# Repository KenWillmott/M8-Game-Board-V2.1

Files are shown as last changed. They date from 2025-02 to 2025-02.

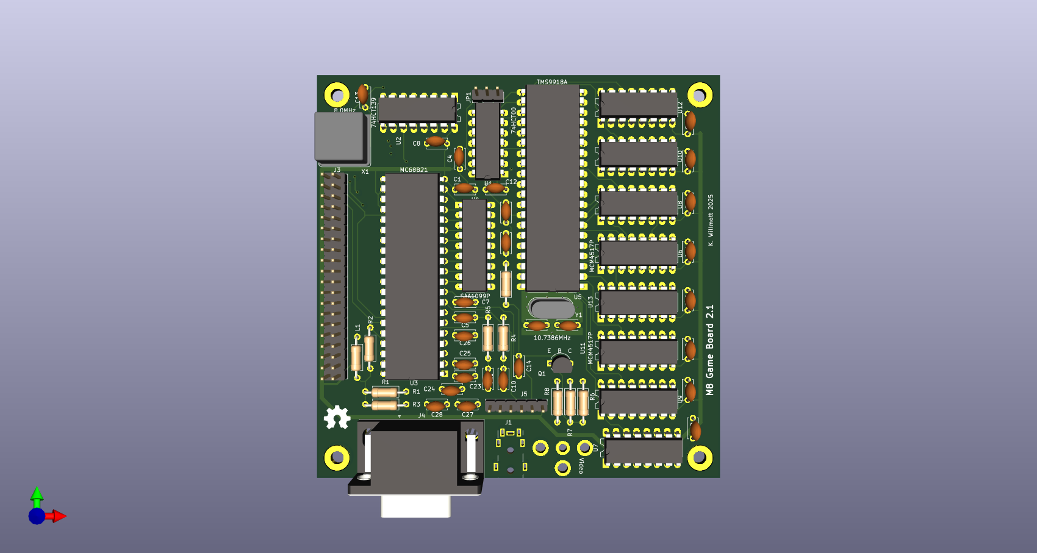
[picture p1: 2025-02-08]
motorino-game-3d.png

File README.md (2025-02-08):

# M8-Game-Board-V2.1
Audio Video Joystick card for M8 bus


This board replaces the first game board, which was not fully working or fully M8 compatible.

It has a TMS9918A video processor with composite video output, stereo sound output from a Philips SAA1099 IC, and one Atari style joystick port. The sound IC and joystick are interfaced via an MC6821 PIA.

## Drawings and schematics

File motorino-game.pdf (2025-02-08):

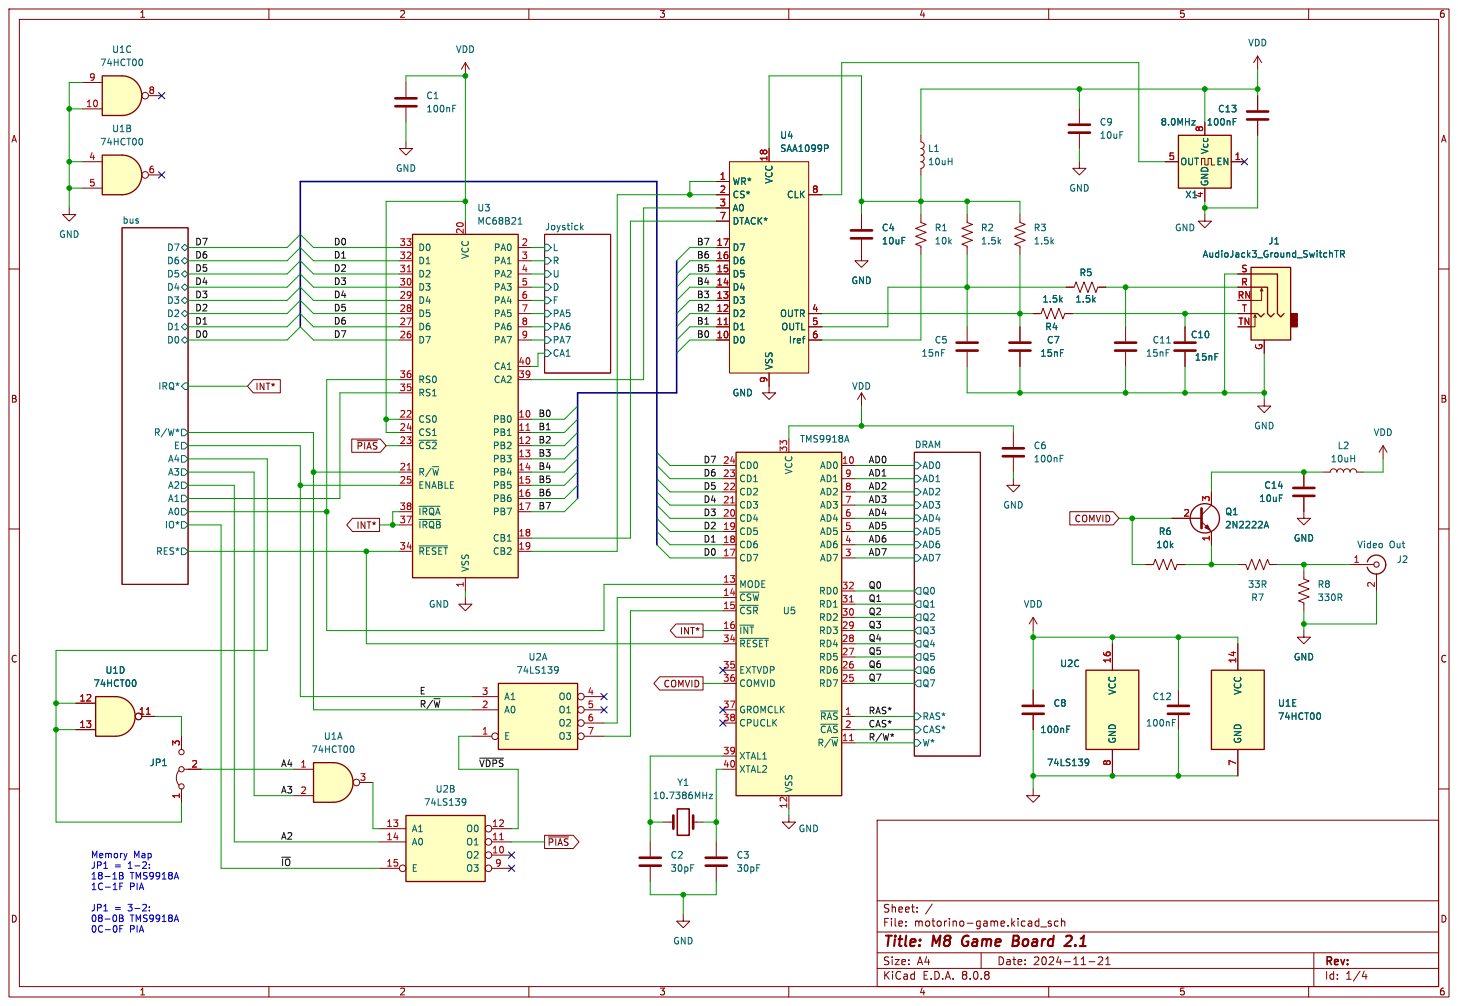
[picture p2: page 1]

File: motorino-game.kicad_sch Sheet: /AD7 AD1 AD2 AD3 AD4 AD5 AD6 AD0 W* RAS* CAS* Q0 Q3 Q1 Q2 Q6 Q7 Q4 Q5 DRAM

Id: 1/4 Title: M8 Game Board 2.1

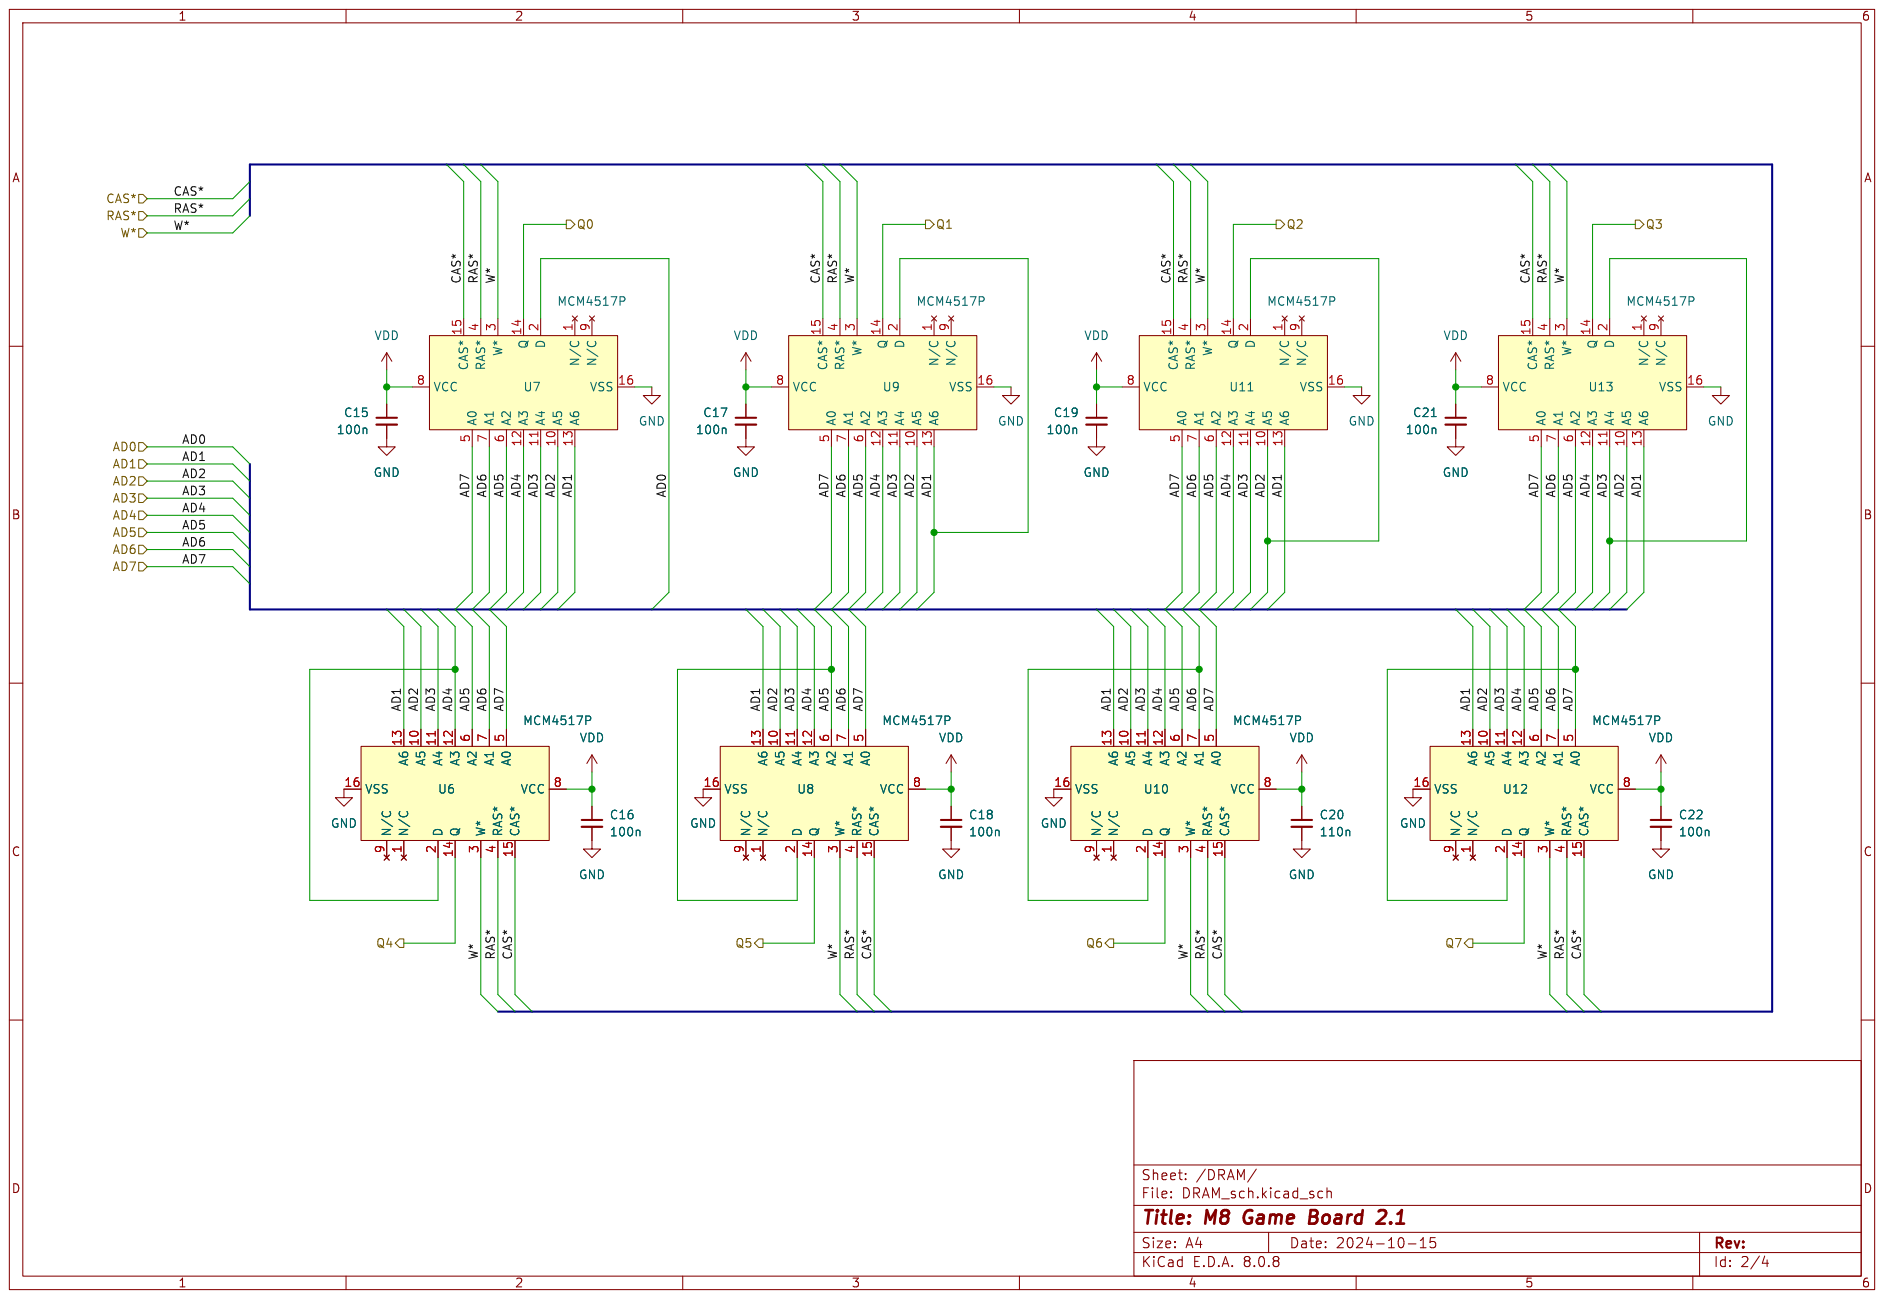
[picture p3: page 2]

Id: 2/4 Title: M8 Game Board 2.1

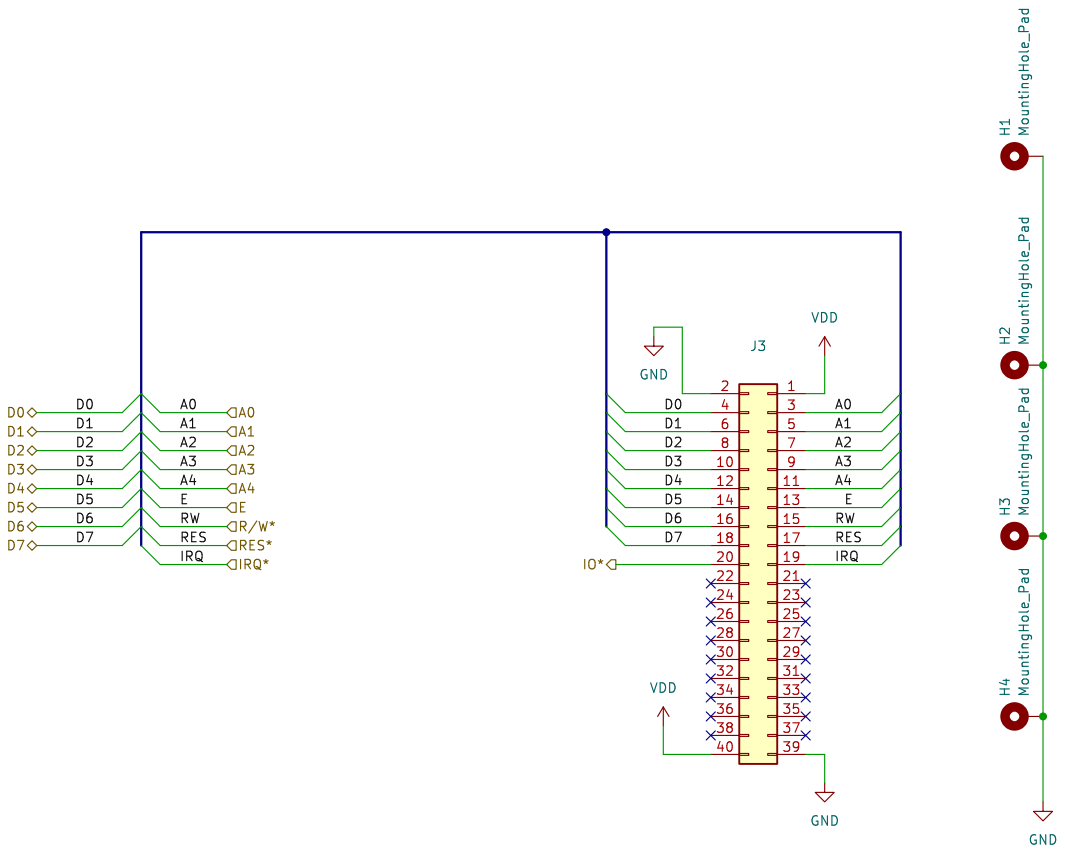
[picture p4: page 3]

Id: 3/4 Title: M8 Game Board 2.1

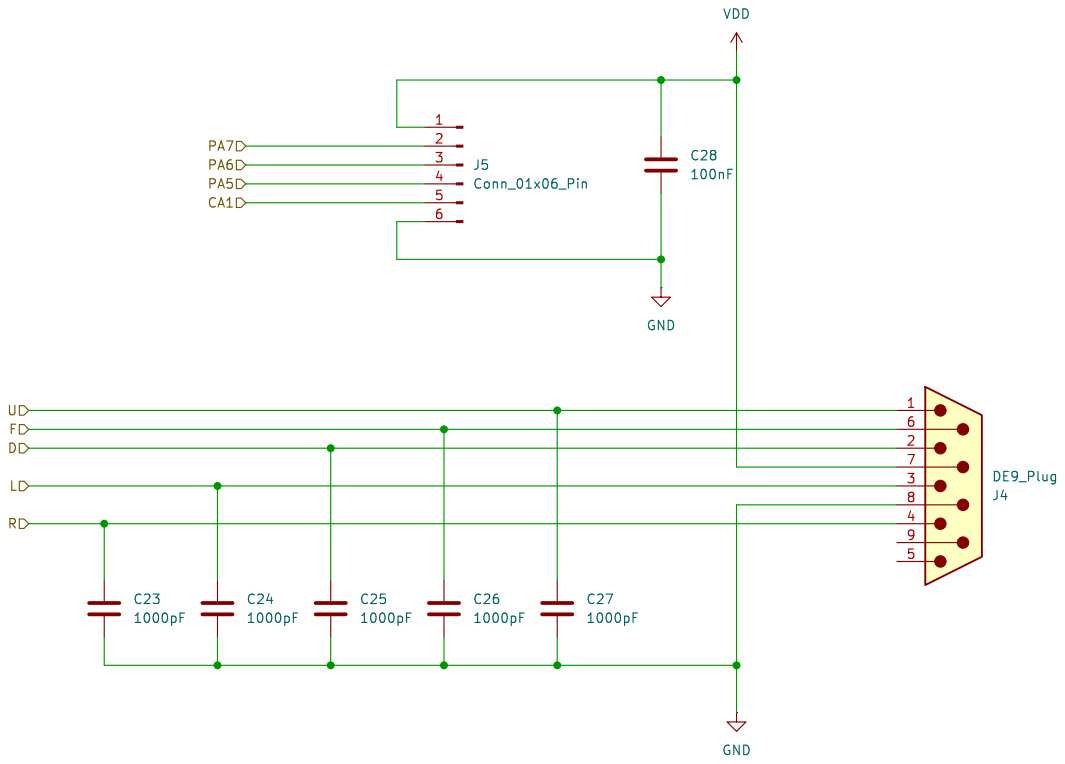
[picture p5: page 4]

Id: 4/4 Title: File: Joystick_sch.kicad_sch Sheet: /Joystick/ C25

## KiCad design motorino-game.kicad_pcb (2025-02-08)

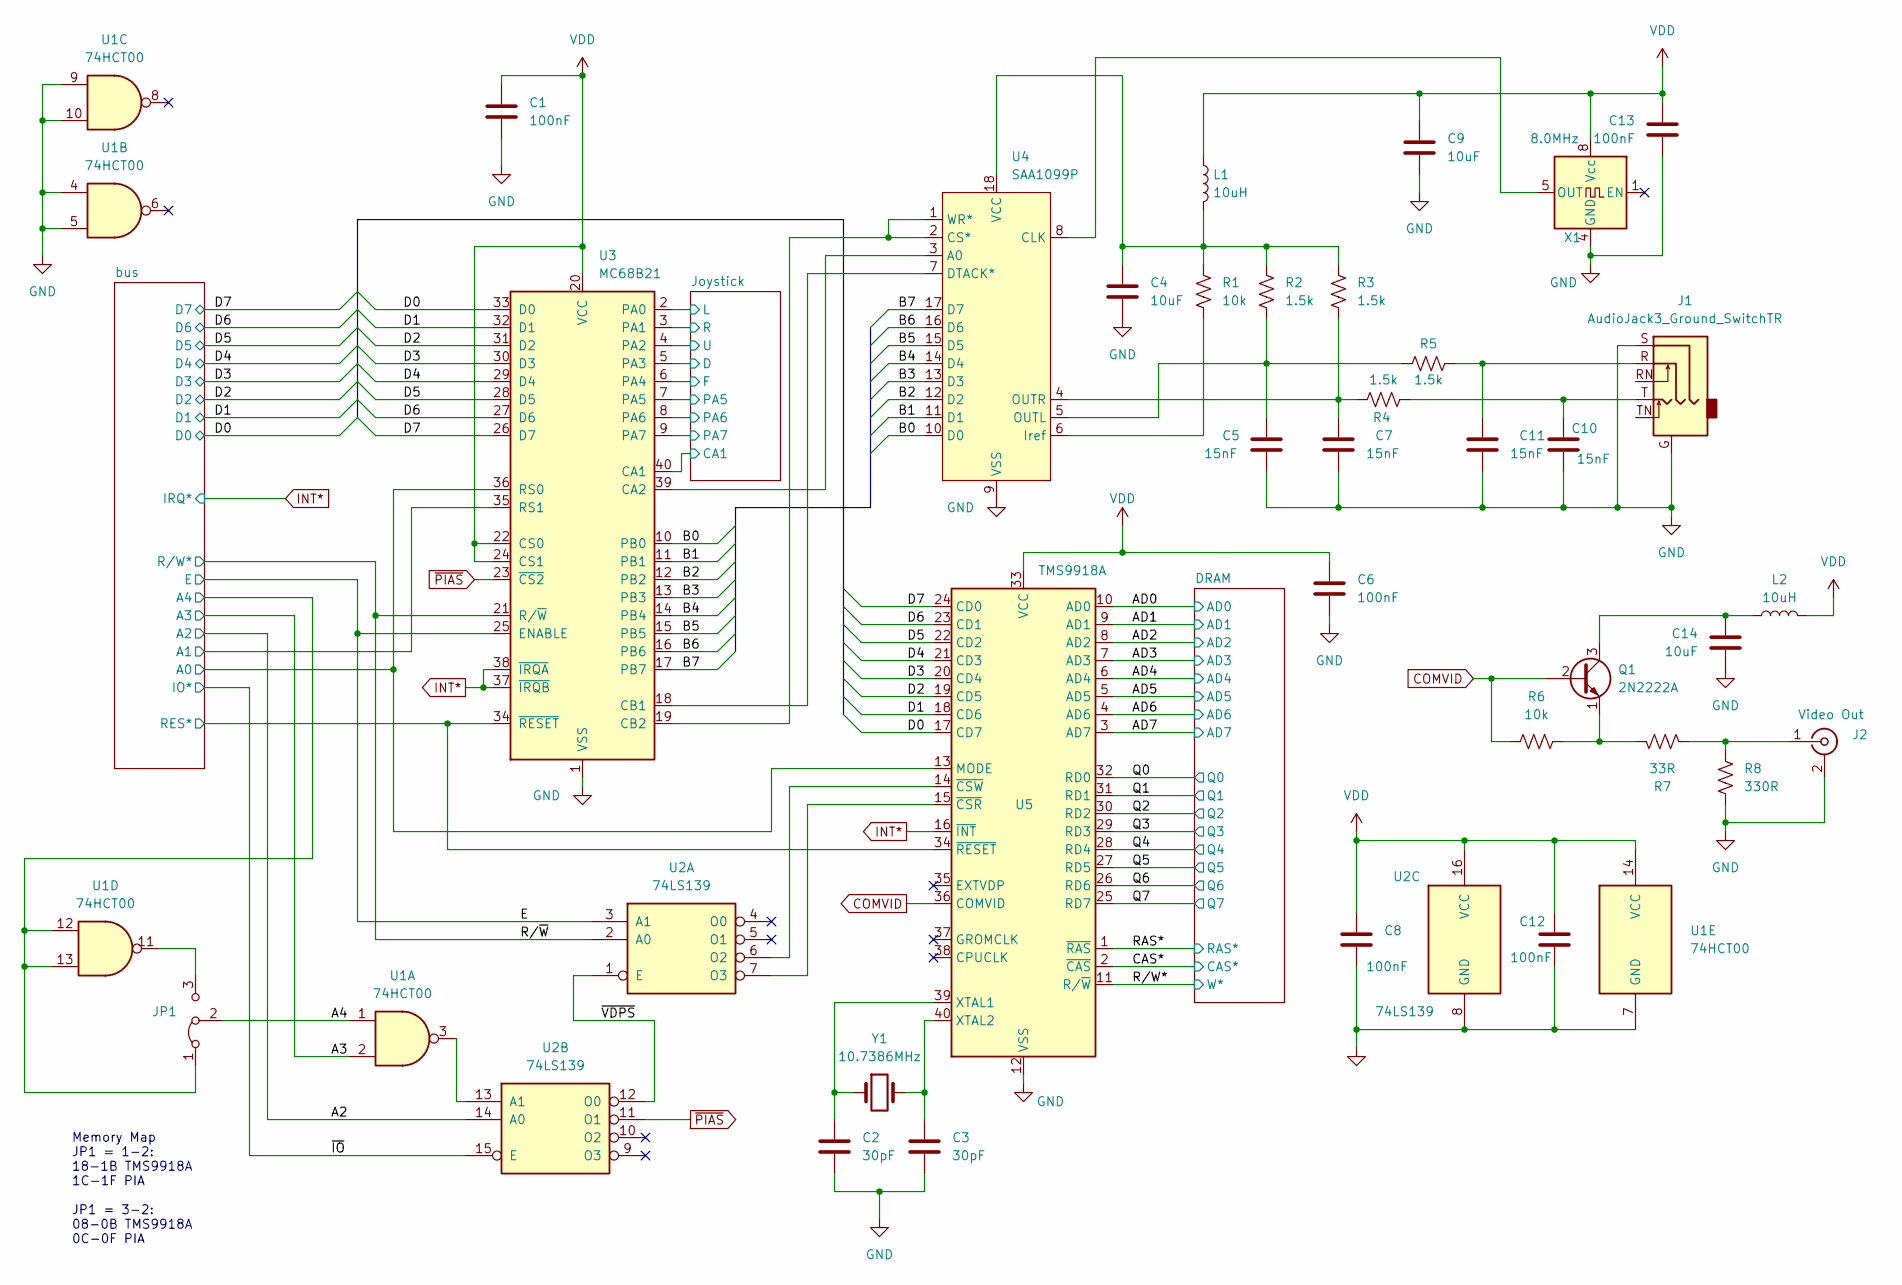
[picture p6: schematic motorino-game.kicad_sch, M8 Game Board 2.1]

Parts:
C1, C6, C8, C12, C13: 100nF; C_Disc_D5.0mm_W2.5mm_P5.00mm
C2, C3: 30pF; C_Disc_D5.0mm_W2.5mm_P5.00mm
C4, C9, C14: 10uF; C_Disc_D5.0mm_W2.5mm_P5.00mm
C5, C7, C10, C11: 15nF; C_Disc_D5.0mm_W2.5mm_P5.00mm
J1: AudioJack3_Ground_SwitchTR; Jack_3.5mm_CUI_SJ3-350113A-SMT_Horizontal
J2: Video Out; RCA jack
JP1: Jumper_3_Bridged12; PinHeader_1x03_P2.54mm_Vertical
L1, L2: 10uH; R_Axial_DIN0207_L6.3mm_D2.5mm_P10.16mm_Horizontal
Q1: 2N2222A; TO-92_Inline_Wide
R1, R6: 10k; R_Axial_DIN0207_L6.3mm_D2.5mm_P10.16mm_Horizontal
R2, R3, R4, R5: 1.5k; R_Axial_DIN0207_L6.3mm_D2.5mm_P10.16mm_Horizontal
R7: 33R; R_Axial_DIN0207_L6.3mm_D2.5mm_P10.16mm_Horizontal
R8: 330R; R_Axial_DIN0207_L6.3mm_D2.5mm_P10.16mm_Horizontal
U1: 74HCT00; DIP-14_W7.62mm_LongPads
U2: 74LS139; DIP-16_W7.62mm_LongPads
U3: MC68B21; DIP-40_W15.24mm
U4: SAA1099P; DIP-18_W7.62mm_LongPads
U5: TMS9918A; DIP-40_W15.24mm_LongPads
X1: 8.0MHz; Oscillator_DIP-8
Y1: 10.7386MHz; Crystal_HC49-U_Vertical

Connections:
/A2: U2.14 (A0); also elsewhere on the board
/A3: U1.2; also elsewhere on the board
/A4: JP1.2 (C), U1.1
/AD0: U5.10 (AD0); also elsewhere on the board
/AD1: U5.9 (AD1); also elsewhere on the board
/AD2: U5.8 (AD2); also elsewhere on the board
/AD3: U5.7 (AD3); also elsewhere on the board
/AD4: U5.6 (AD4); also elsewhere on the board
/AD5: U5.5 (AD5); also elsewhere on the board
/AD6: U5.4 (AD6); also elsewhere on the board
/AD7: U5.3 (AD7); also elsewhere on the board
/B0: U3.10 (PB0), U4.10 (D0)
/B1: U3.11 (PB1), U4.11 (D1)
/B2: U3.12 (PB2), U4.12 (D2)
/B3: U3.13 (PB3), U4.13 (D3)
/B4: U3.14 (PB4), U4.14 (D4)
/B5: U3.15 (PB5), U4.15 (D5)
/B6: U3.16 (PB6), U4.16 (D6)
/B7: U3.17 (PB7), U4.17 (D7)
/CAS*: U5.2 (~CAS); also elsewhere on the board
/D0: U3.33 (D0), U5.17 (CD7); also elsewhere on the board
/D1: U3.32 (D1), U5.18 (CD6); also elsewhere on the board
/D2: U3.31 (D2), U5.19 (CD5); also elsewhere on the board
/D3: U3.30 (D3), U5.20 (CD4); also elsewhere on the board
/D4: U3.29 (D4), U5.21 (CD3); also elsewhere on the board
/D5: U3.28 (D5), U5.22 (CD2); also elsewhere on the board
/D6: U3.27 (D6), U5.23 (CD1); also elsewhere on the board
/D7: U3.26 (D7), U5.24 (CD0); also elsewhere on the board
/E: U2.3 (A1), U3.25 (ENABLE); also elsewhere on the board
/Joystick/CA1: U3.40 (CA1); also elsewhere on the board
/Joystick/D: U3.5 (PA3); also elsewhere on the board
/Joystick/F: U3.6 (PA4); also elsewhere on the board
/Joystick/L: U3.2 (PA0); also elsewhere on the board
/Joystick/PA5: U3.7 (PA5); also elsewhere on the board
/Joystick/PA6: U3.8 (PA6); also elsewhere on the board
/Joystick/PA7: U3.9 (PA7); also elsewhere on the board
/Joystick/R: U3.3 (PA1); also elsewhere on the board
/Joystick/U: U3.4 (PA2); also elsewhere on the board
/Q0: U5.32 (RD0); also elsewhere on the board
/Q1: U5.31 (RD1); also elsewhere on the board
/Q2: U5.30 (RD2); also elsewhere on the board
/Q3: U5.29 (RD3); also elsewhere on the board
/Q4: U5.28 (RD4); also elsewhere on the board
/Q5: U5.27 (RD5); also elsewhere on the board
/Q6: U5.26 (RD6); also elsewhere on the board
/Q7: U5.25 (RD7); also elsewhere on the board
/RAS*: U5.1 (~RAS); also elsewhere on the board
/R/W*: U5.11 (R/~W); also elsewhere on the board
/R/~W: U2.2 (A0), U3.21 (R/~W); also elsewhere on the board
/bus/A0: U3.36 (RS0), U5.13 (MODE); also elsewhere on the board
/bus/A1: U3.35 (RS1); also elsewhere on the board
/bus/A4: JP1.1 (A), U1.12, U1.13; also elsewhere on the board
/bus/RES: U3.34 (~RESET), U5.34 (~RESET); also elsewhere on the board
/~IO: U2.15 (E); also elsewhere on the board
/~VDPS: U2.1 (E), U2.12 (O0)
COMVID: Q1.2 (B), R6.1, U5.36 (COMVID)
GND: C1.2, C2.2, C3.2, C4.2, C5.2, C6.2, C7.2, C8.2, C9.2, C10.2, C11.2, C12.2, C13.2, C14.2, J1.G, J1.S, J2.2 (Ext), R8.2, U1.4, U1.5, U1.7 (GND), U1.9, U1.10, U2.8 (GND), U3.1 (VSS), U4.9 (VSS), U5.12 (VSS), X1.4 (GND); also elsewhere on the board
INT*: U3.37 (~IRQB), U3.38 (~IRQA), U5.16 (~INT); also elsewhere on the board
unnamed: C10.1, J1.T, R4.1
unnamed: C11.1, J1.R, R5.1
unnamed: J2.1 (In), R7.1, R8.1
unnamed: JP1.3 (B), U1.11
unnamed: C14.1, L2.2, Q1.3 (C)
unnamed: Q1.1 (E), R6.2, R7.2
unnamed: U2.6 (O2), U5.14 (~CSW)
unnamed: U2.7 (O3), U5.15 (~CSR)
unnamed: U1.3, U2.13 (A1)
unnamed: U3.39 (CA2), U4.3 (A0)
unnamed: U3.18 (CB1), U4.7 (DTACK*)
unnamed: U3.19 (CB2), U4.1 (WR*), U4.2 (CS*)
unnamed: U4.8 (CLK), X1.5 (OUT)
unnamed: R1.2, U4.6 (Iref)
unnamed: C5.1, R2.2, R5.2, U4.5 (OUTL)
unnamed: C7.1, R3.2, R4.2, U4.4 (OUTR)
unnamed: C4.1, L1.2, R1.1, R2.1, R3.1, U4.18 (VCC)
unnamed: C2.1, U5.39 (XTAL1), Y1.1
unnamed: C3.1, U5.40 (XTAL2), Y1.2
VDD: C1.1, C6.1, C8.1, C9.1, C12.1, C13.1, L1.1, L2.1, U1.14 (VCC), U2.16 (VCC), U3.20 (VCC), U3.22 (CS0), U3.24 (CS1), U5.33 (VCC), X1.8 (Vcc); also elsewhere on the board
~PIAS: U2.11 (O1), U3.23 (~CS2)

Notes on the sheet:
Memory Map JP1 = 1-2: 18-1B TMS9918A 1C-1F PIA JP1 = 3-2: 08-0B TMS9918A 0C-0F PIA

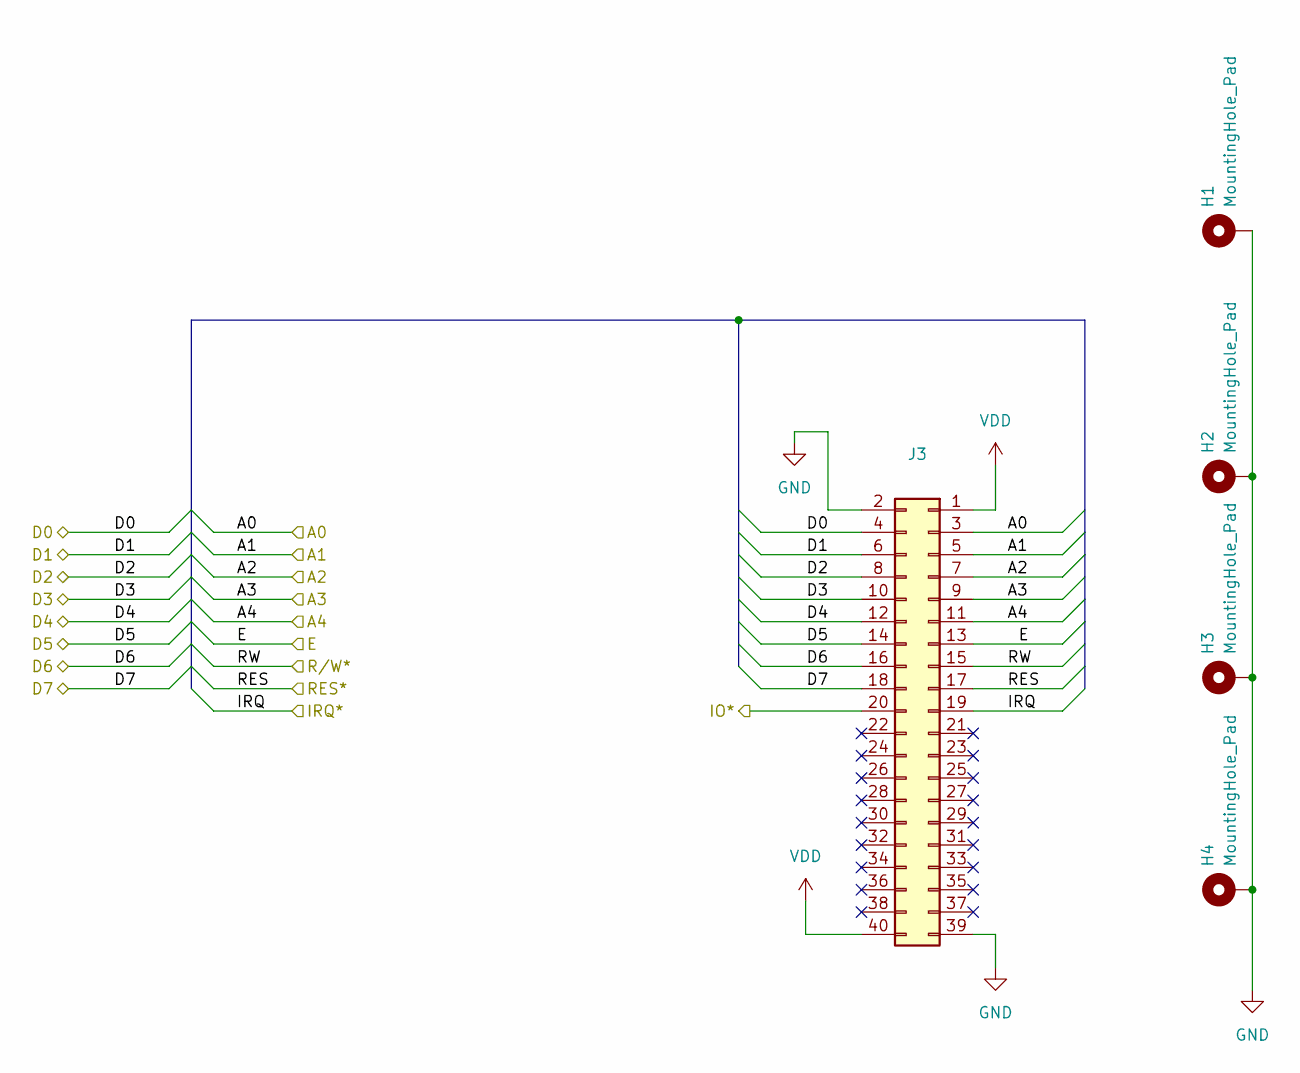
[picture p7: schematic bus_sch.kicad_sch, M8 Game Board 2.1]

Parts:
H1, H2, H3, H4: MountingHole_Pad; MountingHole_3.2mm_M3_Pad
J3: Conn_02x20_Odd_Even; PinHeader_2x20_P2.54mm_Vertical

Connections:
/A2: J3.7; also elsewhere on the board
/A3: J3.9; also elsewhere on the board
/D0: J3.4; also elsewhere on the board
/D1: J3.6; also elsewhere on the board
/D2: J3.8; also elsewhere on the board
/D3: J3.10; also elsewhere on the board
/D4: J3.12; also elsewhere on the board
/D5: J3.14; also elsewhere on the board
/D6: J3.16; also elsewhere on the board
/D7: J3.18; also elsewhere on the board
/E: J3.13; also elsewhere on the board
/R/~W: J3.15; also elsewhere on the board
/bus/A0: J3.3; also elsewhere on the board
/bus/A1: J3.5; also elsewhere on the board
/bus/A4: J3.11; also elsewhere on the board
/bus/RES: J3.17; also elsewhere on the board
/~IO: J3.20; also elsewhere on the board
GND: H1.1, H2.1, H3.1, H4.1, J3.2, J3.39; also elsewhere on the board
INT*: J3.19; also elsewhere on the board
VDD: J3.1, J3.40; also elsewhere on the board

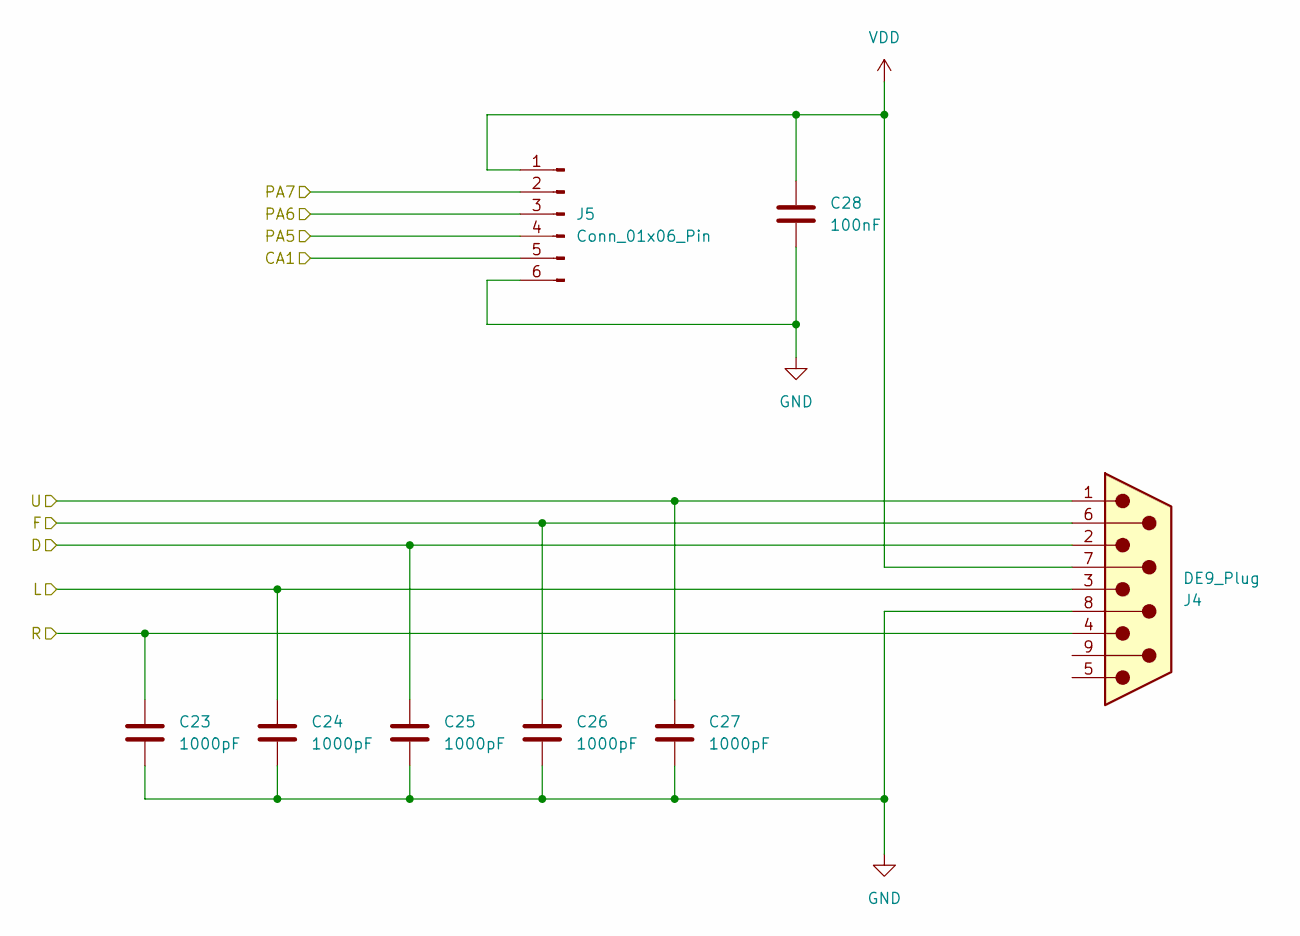
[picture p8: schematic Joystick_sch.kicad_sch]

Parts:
C23, C24, C25, C26, C27: 1000pF; C_Disc_D5.0mm_W2.5mm_P5.00mm
C28: 100nF; C_Disc_D5.0mm_W2.5mm_P5.00mm
J4: DE9_Plug; DSUB-9_Male_Horizontal_P2.77x2.84mm_EdgePinOffset9.90mm_Hou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
J5: Conn_01x06_Pin; PinHeader_1x06_P2.54mm_Vertical

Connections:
/Joystick/CA1: J5.5; also elsewhere on the board
/Joystick/D: C25.1, J4.2; also elsewhere on the board
/Joystick/F: C26.1, J4.6; also elsewhere on the board
/Joystick/L: C24.1, J4.3; also elsewhere on the board
/Joystick/PA5: J5.4; also elsewhere on the board
/Joystick/PA6: J5.3; also elsewhere on the board
/Joystick/PA7: J5.2; also elsewhere on the board
/Joystick/R: C23.1, J4.4; also elsewhere on the board
/Joystick/U: C27.1, J4.1; also elsewhere on the board
GND: C23.2, C24.2, C25.2, C26.2, C27.2, C28.2, J4.8, J5.6; also elsewhere on the board
VDD: C28.1, J4.7, J5.1; also elsewhere on the board

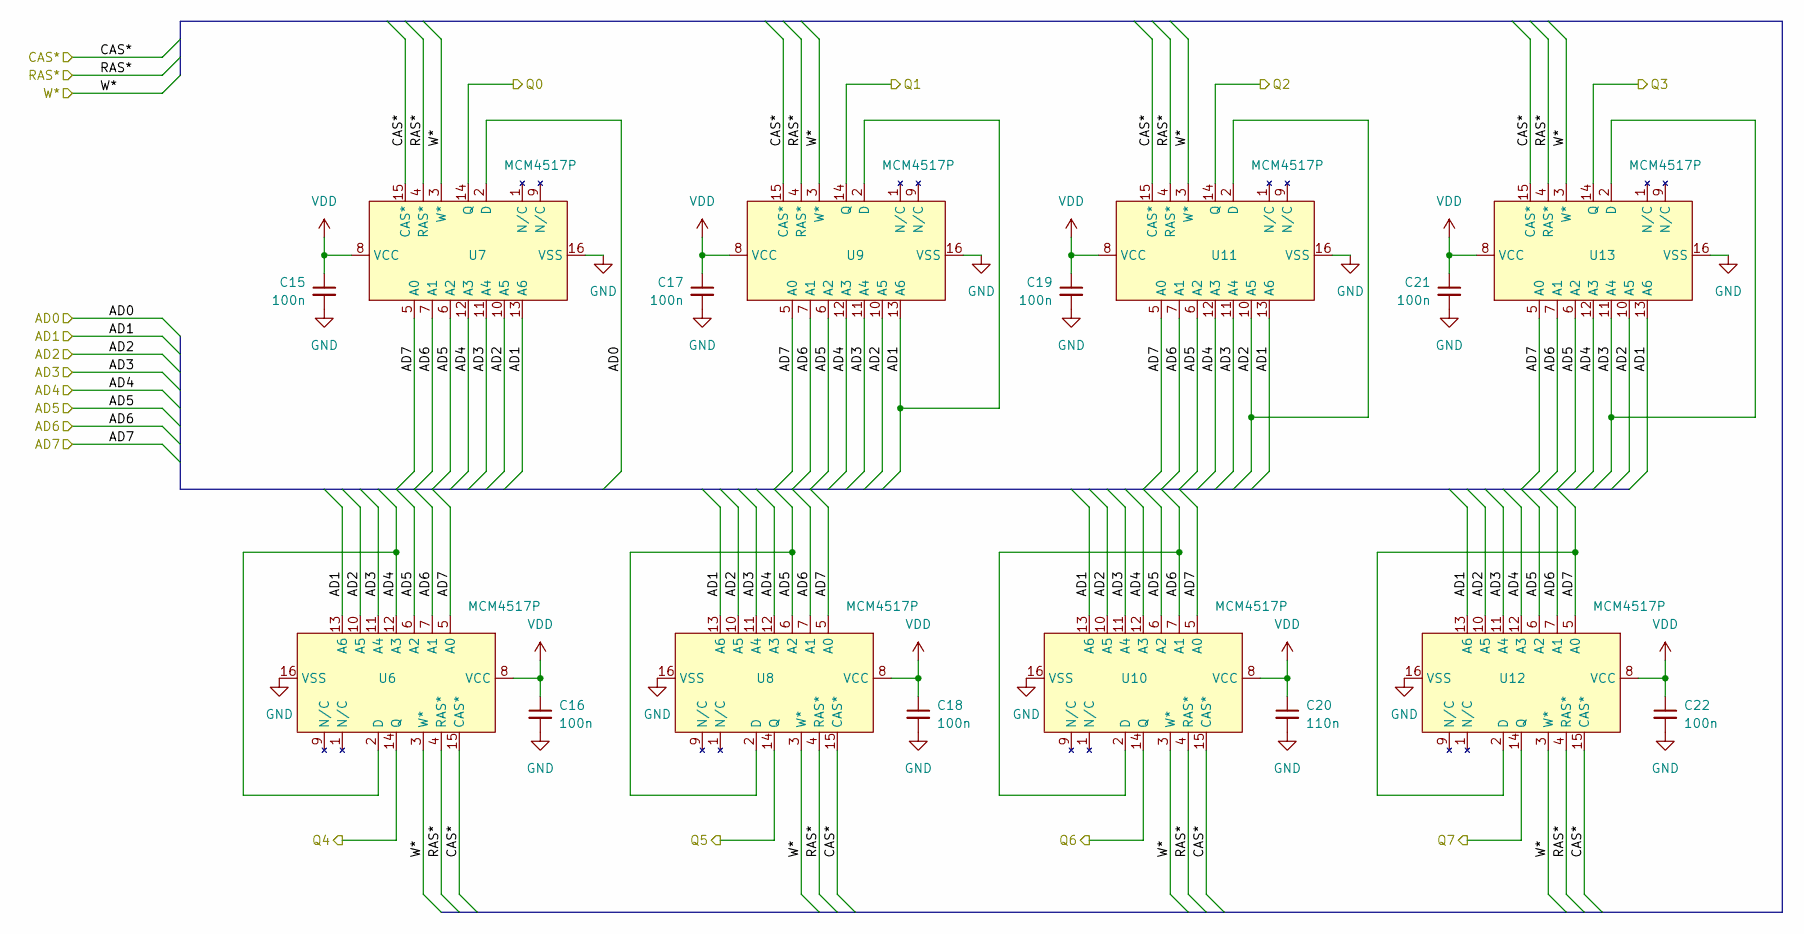
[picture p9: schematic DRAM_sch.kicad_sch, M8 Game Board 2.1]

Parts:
C15, C16, C17, C18, C19, C21, C22: 100n; C_Disc_D5.0mm_W2.5mm_P5.00mm
C20: 110n; C_Disc_D5.0mm_W2.5mm_P5.00mm
U6, U7, U8, U9, U10, U11, U12, U13: MCM4517P; DIP-16_W7.62mm_LongPads

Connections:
/AD0: U7.2 (D); also elsewhere on the board
/AD1: U6.13 (A6), U7.13 (A6), U8.13 (A6), U9.2 (D), U9.13 (A6), U10.13 (A6), U11.13 (A6), U12.13 (A6), U13.13 (A6); also elsewhere on the board
/AD2: U6.10 (A5), U7.10 (A5), U8.10 (A5), U9.10 (A5), U10.10 (A5), U11.2 (D), U11.10 (A5), U12.10 (A5), U13.10 (A5); also elsewhere on the board
/AD3: U6.11 (A4), U7.11 (A4), U8.11 (A4), U9.11 (A4), U10.11 (A4), U11.11 (A4), U12.11 (A4), U13.2 (D), U13.11 (A4); also elsewhere on the board
/AD4: U6.2 (D), U6.12 (A3), U7.12 (A3), U8.12 (A3), U9.12 (A3), U10.12 (A3), U11.12 (A3), U12.12 (A3), U13.12 (A3); also elsewhere on the board
/AD5: U6.6 (A2), U7.6 (A2), U8.2 (D), U8.6 (A2), U9.6 (A2), U10.6 (A2), U11.6 (A2), U12.6 (A2), U13.6 (A2); also elsewhere on the board
/AD6: U6.7 (A1), U7.7 (A1), U8.7 (A1), U9.7 (A1), U10.2 (D), U10.7 (A1), U11.7 (A1), U12.7 (A1), U13.7 (A1); also elsewhere on the board
/AD7: U6.5 (A0), U7.5 (A0), U8.5 (A0), U9.5 (A0), U10.5 (A0), U11.5 (A0), U12.2 (D), U12.5 (A0), U13.5 (A0); also elsewhere on the board
/CAS*: U6.15 (CAS*), U7.15 (CAS*), U8.15 (CAS*), U9.15 (CAS*), U10.15 (CAS*), U11.15 (CAS*), U12.15 (CAS*), U13.15 (CAS*); also elsewhere on the board
/Q0: U7.14 (Q); also elsewhere on the board
/Q1: U9.14 (Q); also elsewhere on the board
/Q2: U11.14 (Q); also elsewhere on the board
/Q3: U13.14 (Q); also elsewhere on the board
/Q4: U6.14 (Q); also elsewhere on the board
/Q5: U8.14 (Q); also elsewhere on the board
/Q6: U10.14 (Q); also elsewhere on the board
/Q7: U12.14 (Q); also elsewhere on the board
/RAS*: U6.4 (RAS*), U7.4 (RAS*), U8.4 (RAS*), U9.4 (RAS*), U10.4 (RAS*), U11.4 (RAS*), U12.4 (RAS*), U13.4 (RAS*); also elsewhere on the board
/R/W*: U6.3 (W*), U7.3 (W*), U8.3 (W*), U9.3 (W*), U10.3 (W*), U11.3 (W*), U12.3 (W*), U13.3 (W*); also elsewhere on the board
GND: C15.2, C16.2, C17.2, C18.2, C19.2, C20.2, C21.2, C22.2, U6.16 (VSS), U7.16 (VSS), U8.16 (VSS), U9.16 (VSS), U10.16 (VSS), U11.16 (VSS), U12.16 (VSS), U13.16 (VSS); also elsewhere on the board
VDD: C15.1, C16.1, C17.1, C18.1, C19.1, C20.1, C21.1, C22.1, U6.8 (VCC), U7.8 (VCC), U8.8 (VCC), U9.8 (VCC), U10.8 (VCC), U11.8 (VCC), U12.8 (VCC), U13.8 (VCC); also elsewhere on the board

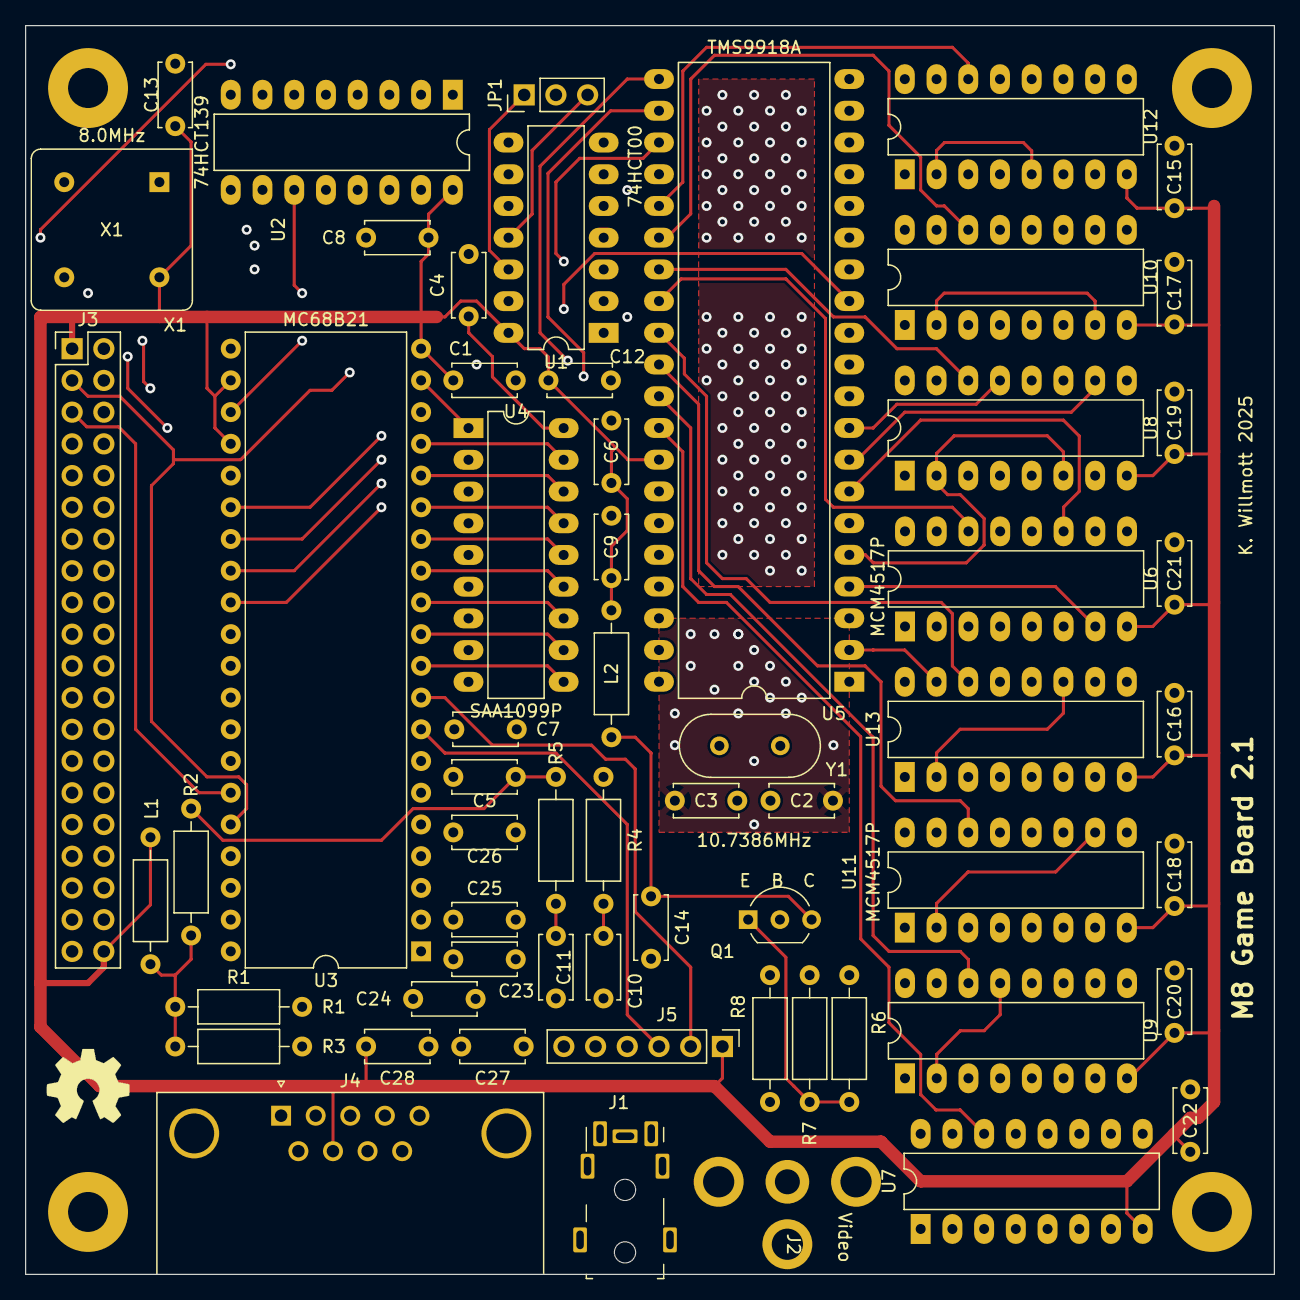
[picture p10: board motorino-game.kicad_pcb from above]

Board: 4 copper layers, 100.0 x 100.0 mm, 64 parts (0 on the bottom side), 79 nets.
